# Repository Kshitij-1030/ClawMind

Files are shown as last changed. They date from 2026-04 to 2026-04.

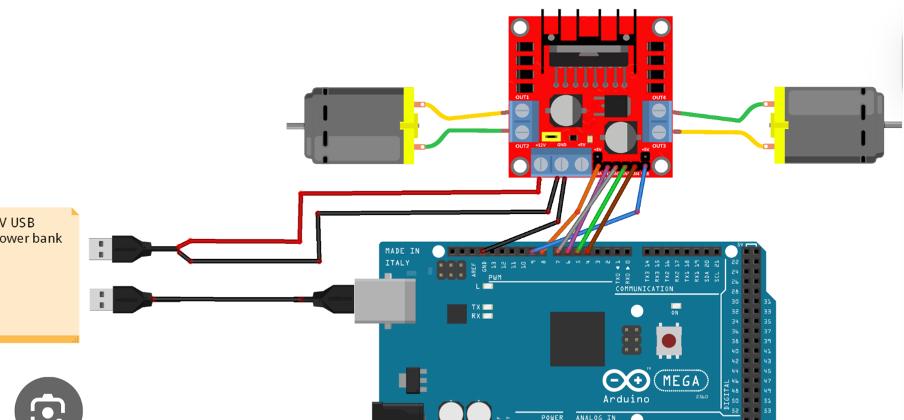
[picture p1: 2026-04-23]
Schematics/dc_motor_wiring.jpeg

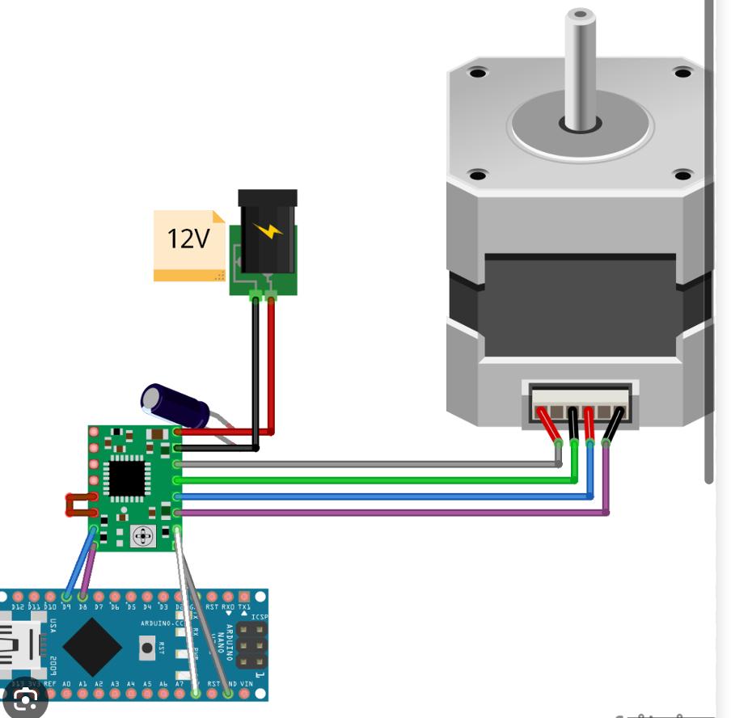
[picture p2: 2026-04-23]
Schematics/stepper_wiring.jpeg

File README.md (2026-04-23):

# ClawMind 🦾

**A hands-free robotic claw machine controlled entirely by head movements — built for accessibility at StarkHacks 2026, Purdue University.**

ClawMind allows anyone, including people with limited hand mobility, to control a physical robotic claw using only their face. No hands required.

---

## Demo

ClawMind Demo (https://youtu.be/r2palXzuYOI)

> Tilt your head. Move the claw. Open your mouth. Grab.

---

## How It Works

A laptop webcam tracks your face in real time using MediaPipe FaceMesh (478 facial landmarks). Head gestures are converted into movement commands that travel over WiFi to a Raspberry Pi, which forwards them to an Arduino Nano controlling the motors.

### Control Scheme

| Gesture | Action |
|---|---|
| Tilt head left | Move claw left |
| Tilt head right | Move claw right |
| Look up | Move claw forward |
| Look down | Move claw back |
| Open mouth | Trigger grab sequence |

### Grab Sequence (automatic)
1. Z axis motor lowers the claw
2. Servo closes and grabs the object
3. Z axis motor retracts back up

---

## System Architecture

```
Laptop (webcam)
    ↓ MediaPipe FaceMesh — detects head tilt, nod, mouth
face_control.py — converts gestures to commands
    ↓ writes to /tmp/claw_command.txt
cmd_sender.py — reads file, HTTP POSTs to Pi
    ↓ WiFi (HTTP POST)
Raspberry Pi 4 — bridge.py HTTP server (port 8888)
    ↓ USB serial (9600 baud)
Arduino Nano — motor control firmware
    ↓
L298N driver → TT DC motors (X and Z axis)
A4988 driver → Stepper motor (Y axis)
MG90S Servo → Claw grip
```

---

## Tech Stack

- **Computer Vision:** Python, MediaPipe FaceMesh, OpenCV, NumPy
- **Communication:** HTTP over WiFi (laptop → Pi), USB Serial (Pi → Arduino)
- **Hardware:** Raspberry Pi 4, Arduino Nano, L298N motor driver, A4988 stepper driver, MG90S servo, TT DC motors
- **Cloud:** Viam robotics platform (viam-server on Pi, registered on app.viam.com)
- **Mechanical:** Custom 3D printed gantry frame (STEP + STL files in `/cad`)

---

## Project Structure

```
ClawMind/
├── README.md
├── Code/
│   ├── laptop/
│   │   ├── face_control.py
│   │   └── cmd_sender.py
│   ├── pi/
│   │   └── bridge.py
│   └── arduino/
│       └── Arduino.ino
├── cad/
│   └── *.step / *.stl
└── schematics/
    ├── stepper_wiring.jpg
    └── dc_motor_wiring.jpg
```

---

## Setup & Installation

### Laptop
```bash
# Create virtual environment for mediapipe
python3.11 -m venv ~/venv_mediapipe
source ~/venv_mediapipe/bin/activate
pip install mediapipe==0.10.9 opencv-python numpy

# Run face control
python face_control.py
```

```bash
# In a second terminal — send commands to Pi
python3 cmd_sender.py
```

### Raspberry Pi
```bash
pip3 install pyserial --break-system-packages
python3 bridge.py
```

### Arduino
Open `ClawMind.ino` in Arduino IDE, select **Arduino Nano** board and the correct port, then upload.

---

## Key Technical Challenges

**Protobuf version conflict** — MediaPipe and Viam SDK required incompatible versions of protobuf. Solved by running them in separate Python virtual environments communicating through a shared local file.

**Nod detection accuracy** — Early versions incorrectly triggered forward/back commands when the user turned their head sideways. Fixed by measuring the nose's vertical position relative to the ear midpoint instead of the nose-to-chin angle.

**3.3V vs 5V logic** — Arduino UNO Q's 3.3V GPIO couldn't reliably drive the L298N and A4988 motor drivers. Switched to Arduino Nano (5V logic) to resolve motor control issues.

---

## The Team

| Name | Role |
|---|---|
| **Kshitij Kesharwani** | Software & Systems — CV pipeline, gesture detection, Raspberry Pi setup, HTTP relay, system architecture |
| **Duna Areny Molne** | Electrical Engineering — motor drivers, Arduino firmware, circuit design, wiring, hardware debugging |
| **Younji Kim** | Mechanical Engineering — CAD design, 3D printing, physical assembly, gantry frame |

---

## Inspiration

The idea was born from Younji's vision of creating something interactive and fun — a project that makes computer vision tangible for people encountering it for the first time. We pushed the concept further by designing it for accessibility: what if someone with limited hand mobility could play a claw machine too?

---

## Built At

**StarkHacks 2026** — Hardware Hackathon at Purdue University
**Table 36**

---

*Built with ❤️ and way too little sleep.*

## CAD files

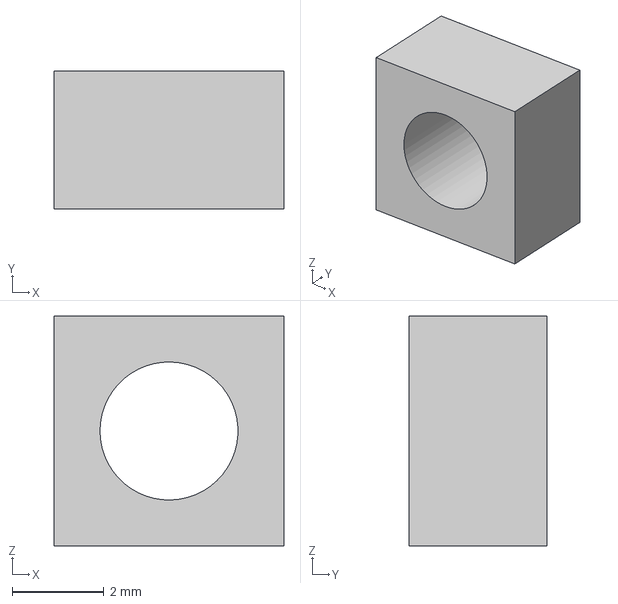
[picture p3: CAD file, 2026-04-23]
cad/ttstringhole.step
5.00 x 3.00 x 5.00 mm

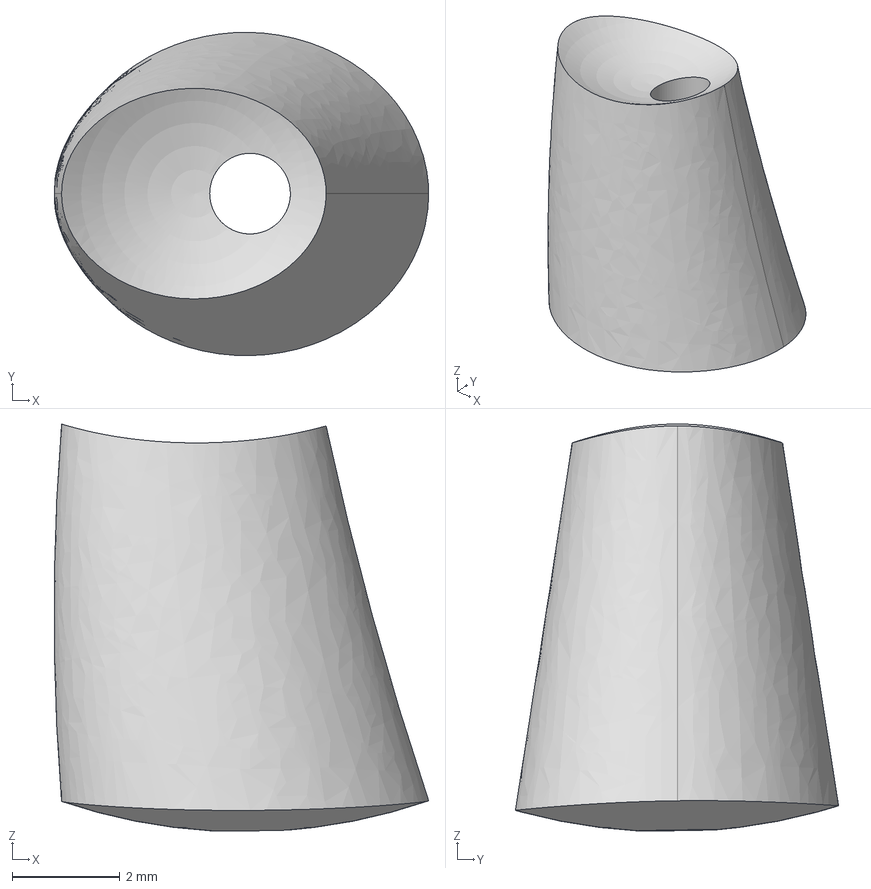
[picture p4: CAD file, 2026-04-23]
cad/claw3.step
6.96 x 6.01 x 7.57 mm

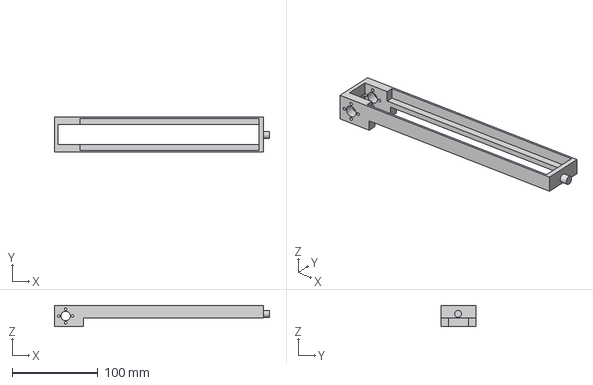
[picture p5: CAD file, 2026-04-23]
cad/rail.step
251.0 x 41.0 x 25.0 mm

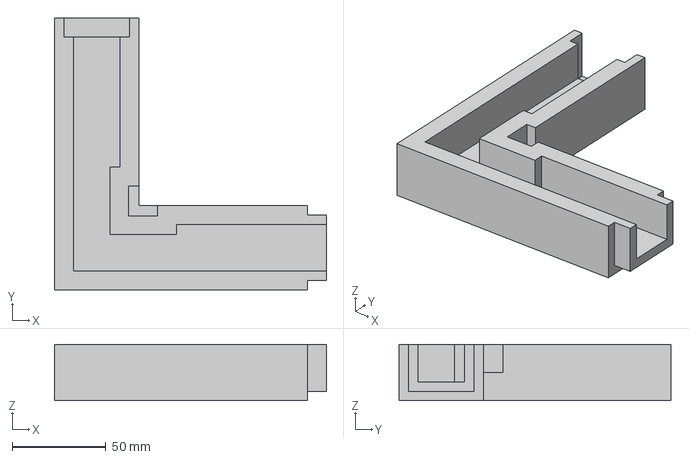
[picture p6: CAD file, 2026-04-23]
cad/topsmall.step
145.0 x 145.0 x 30.0 mm

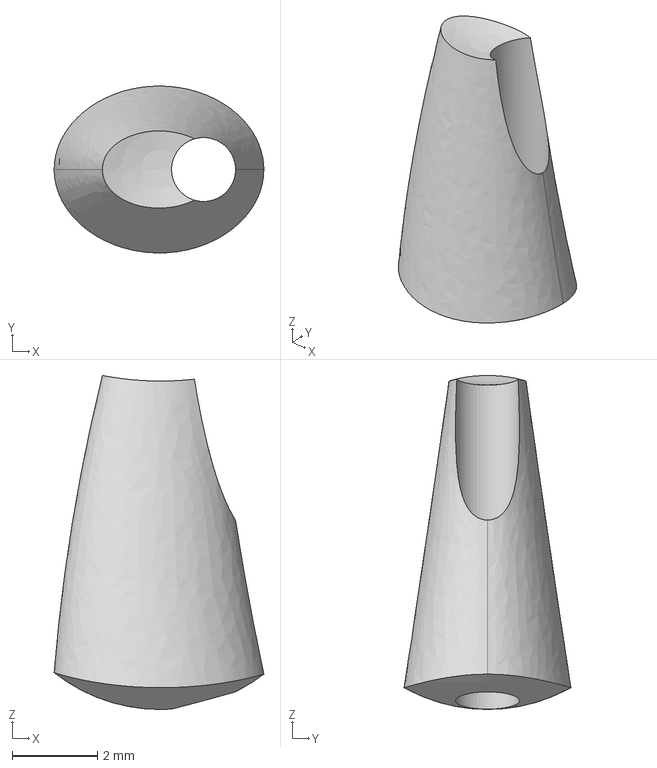
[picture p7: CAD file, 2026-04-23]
cad/claw4.step
4.92 x 3.92 x 7.83 mm

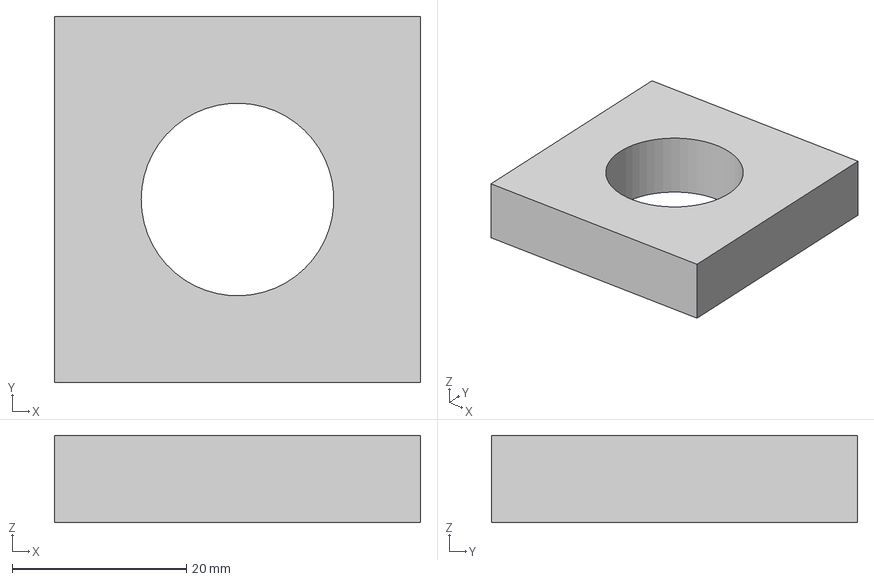
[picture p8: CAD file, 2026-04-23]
cad/bearingsupport.step
42.0 x 42.0 x 10.0 mm

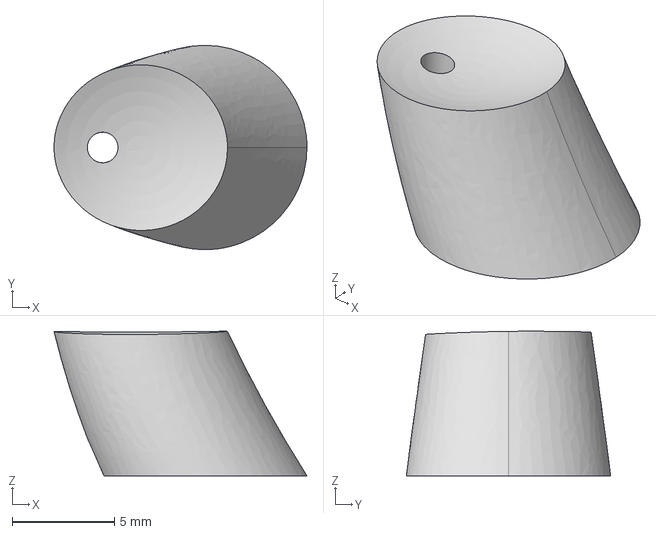
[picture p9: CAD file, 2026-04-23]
cad/claw1.step
12.4 x 10.00 x 7.08 mm

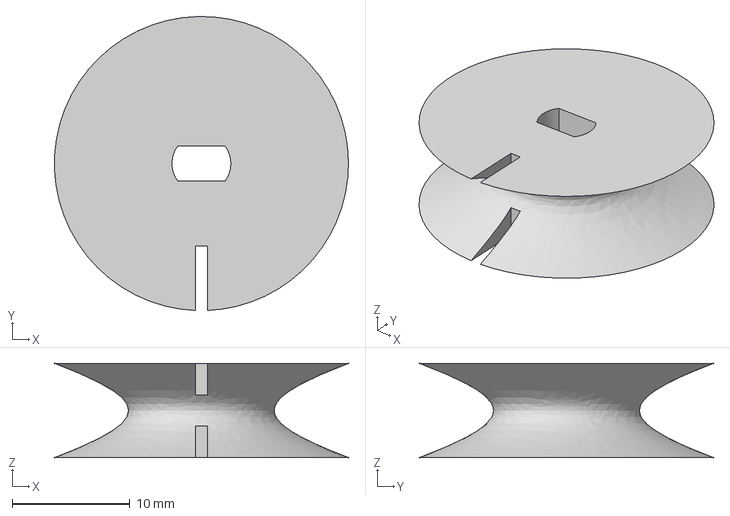
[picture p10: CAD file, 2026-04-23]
cad/stringwheel.step
25.0 x 25.0 x 8.00 mm

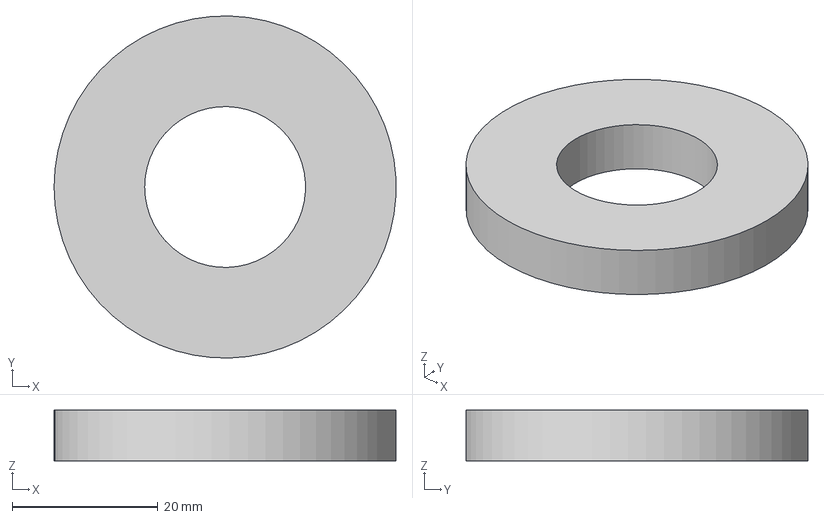
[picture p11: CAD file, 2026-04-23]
cad/bearingwheel.step
47.0 x 47.0 x 7.00 mm

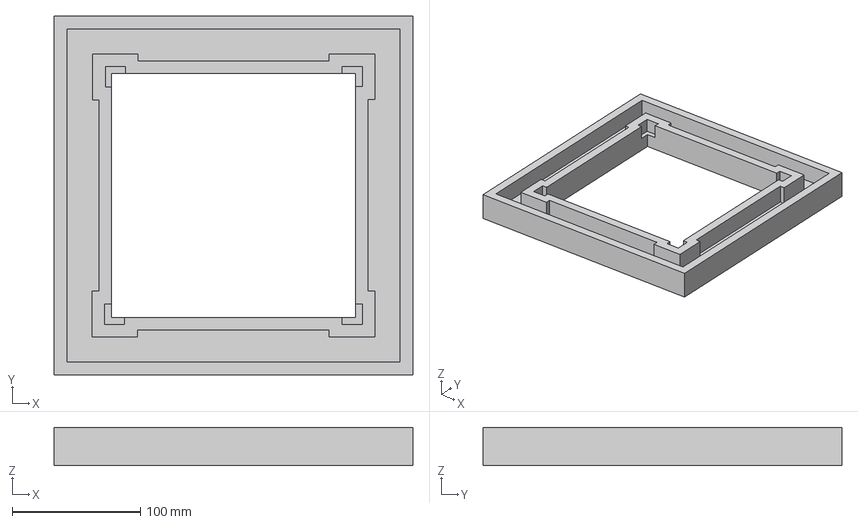
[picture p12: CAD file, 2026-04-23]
cad/top.step
280.0 x 280.0 x 30.0 mm

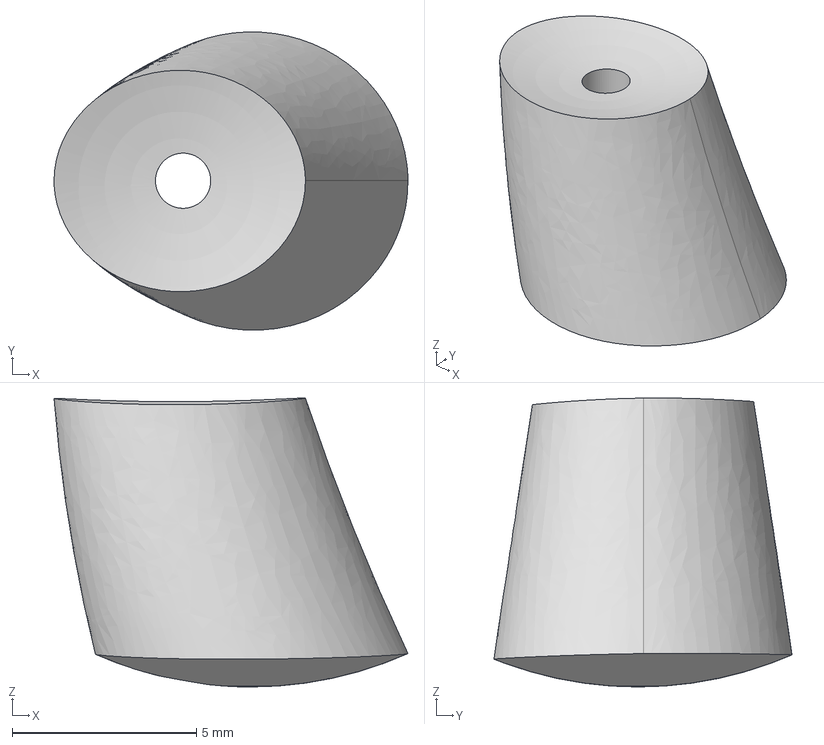
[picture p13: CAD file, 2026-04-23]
cad/claw2.step
9.62 x 8.10 x 7.85 mm

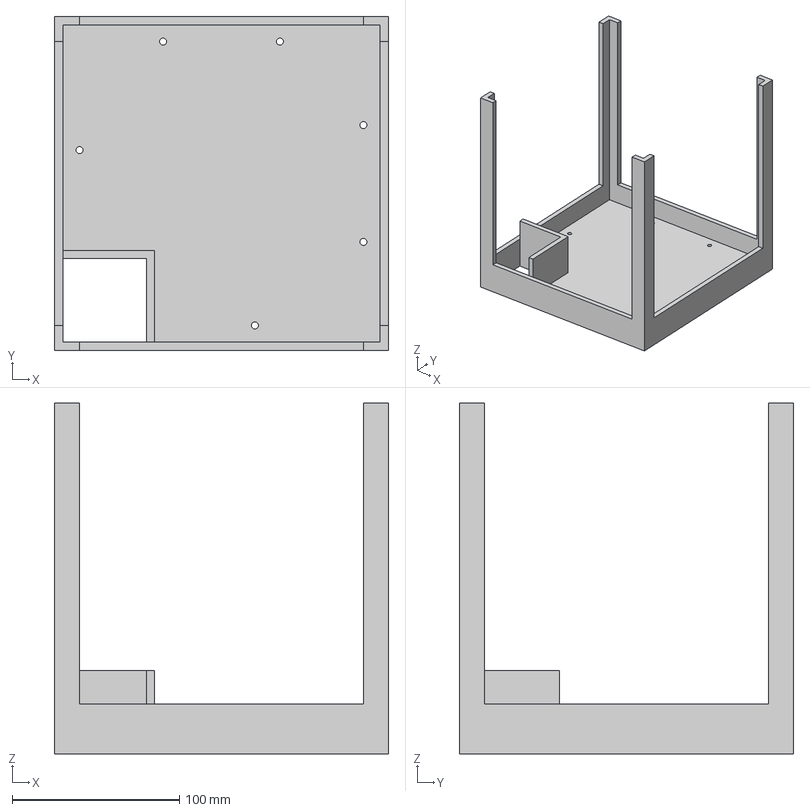
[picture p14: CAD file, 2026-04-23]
cad/bottom.step
200.0 x 200.0 x 210.0 mm

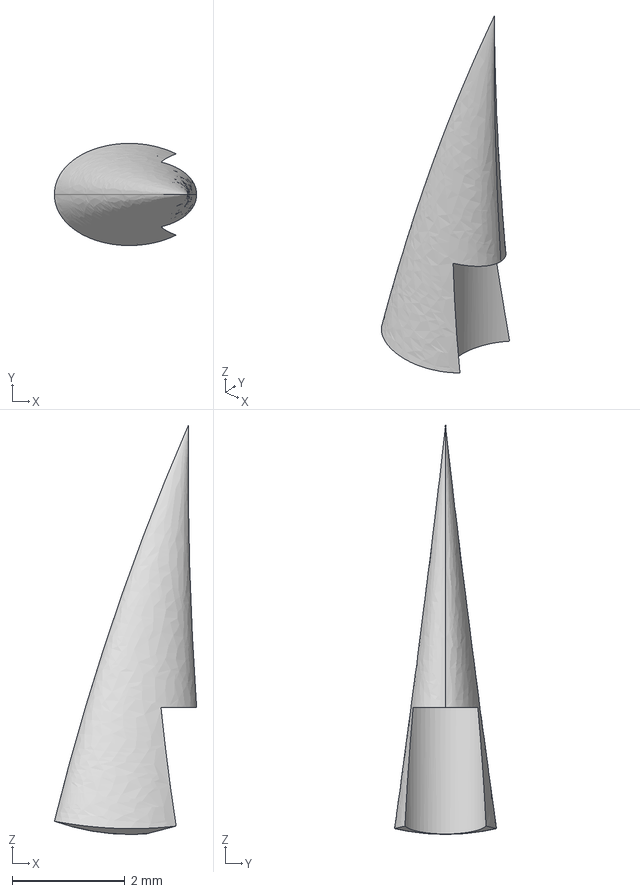
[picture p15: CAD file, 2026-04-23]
cad/claw5.step
2.52 x 1.81 x 7.25 mm

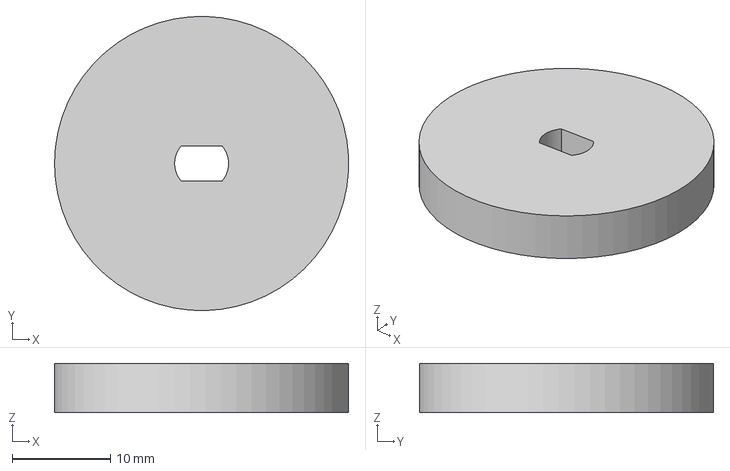
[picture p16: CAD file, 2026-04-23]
cad/wheelx.step
30.0 x 30.0 x 5.00 mm

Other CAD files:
cad/xaxis.step
cad/bearingsupport.stl
cad/bearingwheel.stl
cad/bottom.stl
cad/claw1.stl
cad/claw2.stl
cad/claw3.stl
cad/claw4.stl
cad/claw5.stl
cad/rail.stl
cad/stringwheel.stl
cad/top.stl
cad/topsmall.stl
cad/ttstringhole.stl
cad/wheelx.stl
cad/xaxis.stl

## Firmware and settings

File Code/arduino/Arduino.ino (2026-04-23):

const int STEP = 3;
const int DIR = 2;

const int ENA_X = 9;
const int IN1_X = 8;
const int IN2_X = 7;

const int ENA_C = 10;
const int IN1_C = 11;
const int IN2_C = 12;

const int LIMIT_Y_A = A4;
const int LIMIT_Y_B = A3;

String command = "";

void stopAll() {
  digitalWrite(IN1_X, LOW); digitalWrite(IN2_X, LOW);
  digitalWrite(IN1_C, LOW); digitalWrite(IN2_C, LOW);
}

void stepMotor(bool forward) {
  if (forward && digitalRead(LIMIT_Y_A) == LOW) return;
  if (!forward && digitalRead(LIMIT_Y_B) == LOW) return;
  digitalWrite(DIR, forward ? HIGH : LOW);
  digitalWrite(STEP, HIGH);
  delayMicroseconds(1500);
  digitalWrite(STEP, LOW);
  delayMicroseconds(1500);
}

void setup() {
  Serial.begin(9600);
  pinMode(STEP, OUTPUT);
  pinMode(DIR, OUTPUT);
  pinMode(ENA_X, OUTPUT);
  pinMode(IN1_X, OUTPUT);
  pinMode(IN2_X, OUTPUT);
  pinMode(ENA_C, OUTPUT);
  pinMode(IN1_C, OUTPUT);
  pinMode(IN2_C, OUTPUT);
  pinMode(LIMIT_Y_A, INPUT_PULLUP);
  pinMode(LIMIT_Y_B, INPUT_PULLUP);
  analogWrite(ENA_X, 120);
  analogWrite(ENA_C, 60);
  stopAll();
  Serial.println("Arduino ready");
}

void loop() {
  if (Serial.available()) {
    command = Serial.readStringUntil('\n');
    command.trim();
  }

  // Look left → move right, look right → move left (swapped)
  if (command == "X+") {
    stepMotor(true);   // swapped
  }
  else if (command == "X-") {
    stepMotor(false);  // swapped
  }
  else if (command == "Y+") {
    digitalWrite(IN1_X, LOW); digitalWrite(IN2_X, HIGH);
  }
  else if (command == "Y-") {
    digitalWrite(IN1_X, HIGH); digitalWrite(IN2_X, LOW);
  }
  else if (command == "GO") {
    digitalWrite(IN1_C, HIGH); digitalWrite(IN2_C, LOW);
  }
  else if (command == "OP") {
    digitalWrite(IN1_C, LOW); digitalWrite(IN2_C, HIGH);
  }
  else if (command == "ST") {
    stopAll();
  }

  if (command == "X+" || command == "X-") {
    stepMotor(command == "X+");  // swapped
  }
}

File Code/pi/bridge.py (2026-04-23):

import serial
import time
from http.server import HTTPServer, BaseHTTPRequestHandler

arduino = None
last_command = None

def connect_arduino():
    global arduino
    ports = ['/dev/ttyACM0', '/dev/ttyACM1', '/dev/ttyUSB0', '/dev/ttyUSB1']
    for port in ports:
        try:
            arduino = serial.Serial(port, 9600, timeout=1)
            time.sleep(2)
            print(f"Arduino connected on {port}")
            return True
        except:
            continue
    print("Arduino not found — running without serial")
    return False

def send_to_arduino(cmd):
    global last_command
    if arduino and cmd != last_command:
        try:
            arduino.write((cmd + '\n').encode())
            last_command = cmd
            print(f"Sent to Arduino: {cmd}")
        except Exception as e:
            print(f"Serial error: {e}")

class CommandHandler(BaseHTTPRequestHandler):
    def do_POST(self):
        length = int(self.headers['Content-Length'])
        cmd = self.rfile.read(length).decode().strip()
        send_to_arduino(cmd)
        self.send_response(200)
        self.end_headers()
        self.wfile.write(b"OK")

    def log_message(self, format, *args):
        pass

connect_arduino()
print("Bridge HTTP server running on port 8888...")
server = HTTPServer(('0.0.0.0', 8888), CommandHandler)
server.serve_forever()
